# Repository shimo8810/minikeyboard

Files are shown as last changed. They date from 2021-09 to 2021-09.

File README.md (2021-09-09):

# minikeyboard

## 仕様

- 出力: CV/GATE 信号 (V/Hz)
- 音階: C4-B4 (多分)

## 回路図

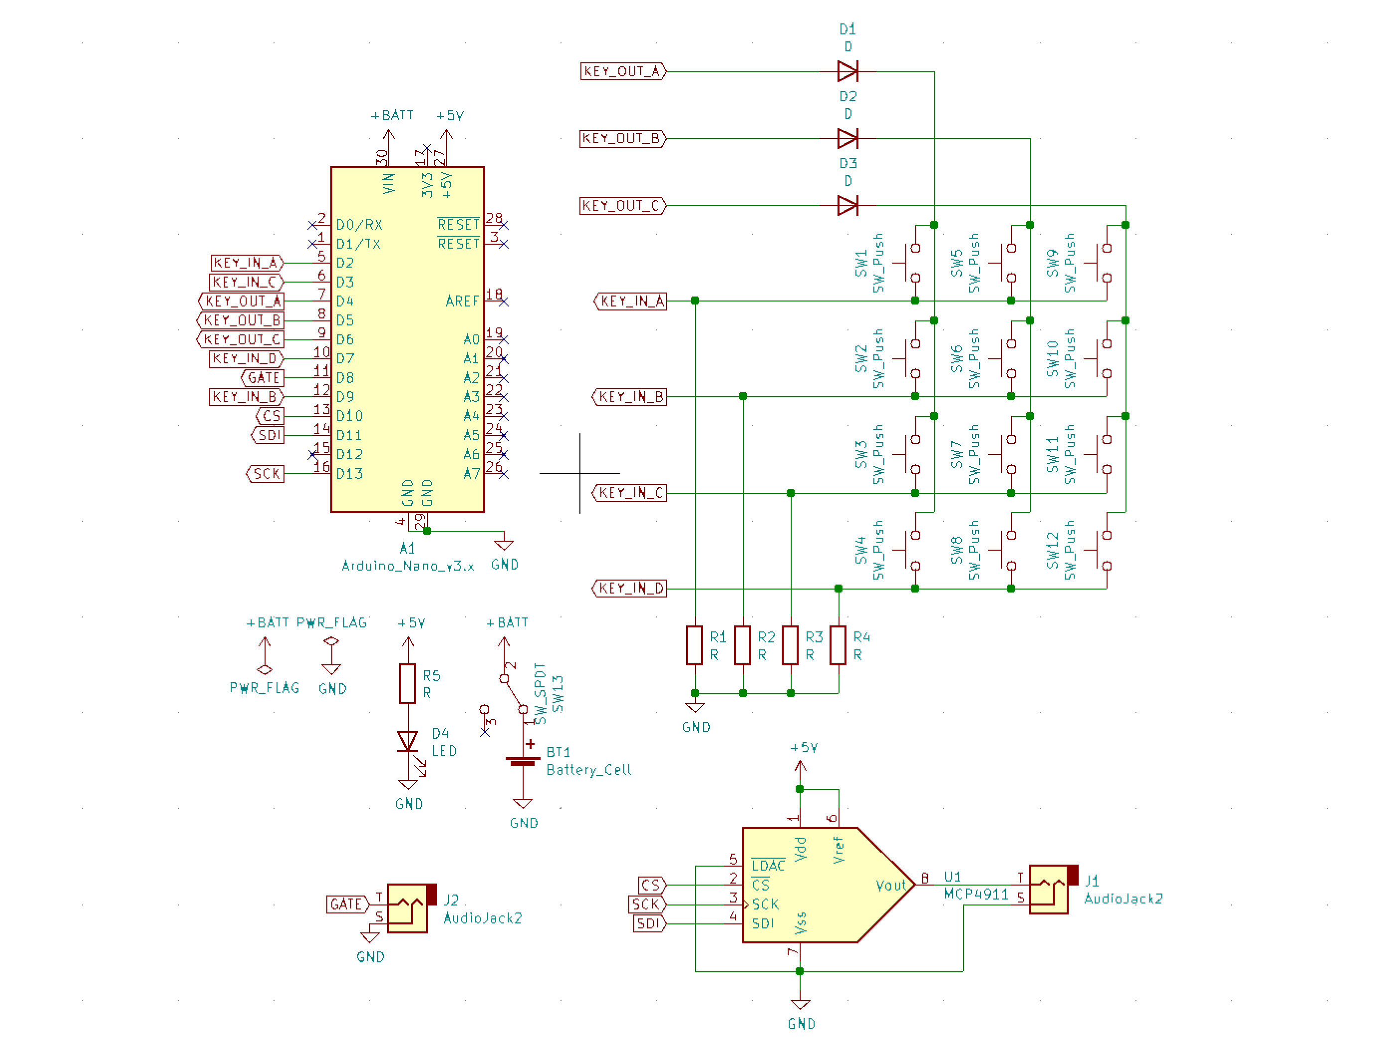
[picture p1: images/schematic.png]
schematic


## 配置

ユニバーサル基板用に配置
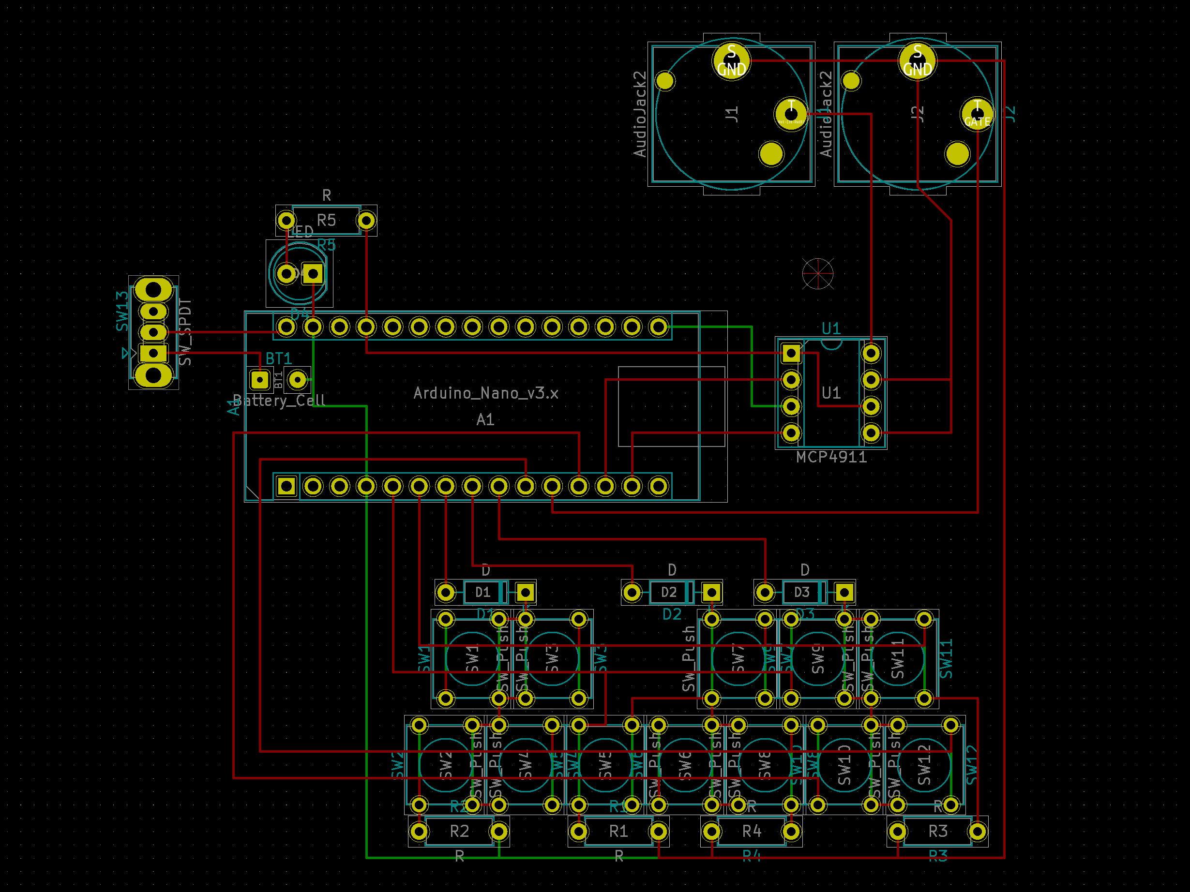
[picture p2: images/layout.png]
layout


## 完成品

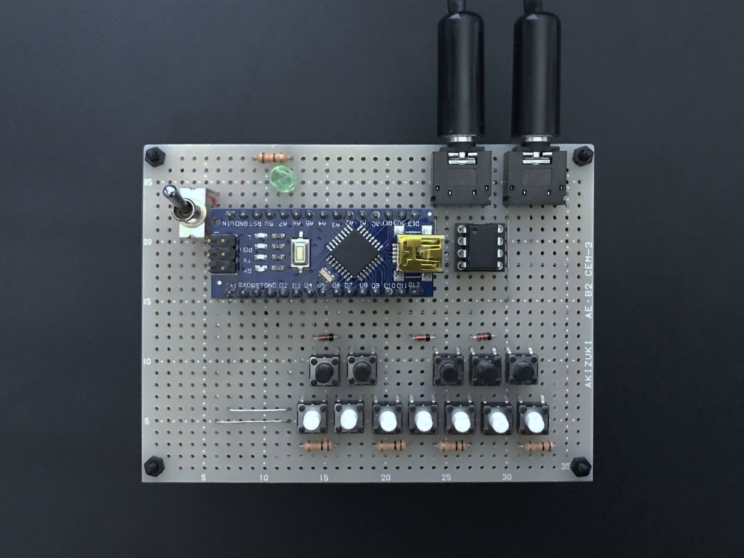
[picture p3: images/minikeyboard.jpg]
minikeyboard


## 参照･参考

- https://info.shimamura.co.jp/digital/support/2020/02/136051
- https://www.arduino.cc/reference/en/libraries/mcp_dac/
- https://moutakusan.hatenablog.com/entry/2020/10/23/071000

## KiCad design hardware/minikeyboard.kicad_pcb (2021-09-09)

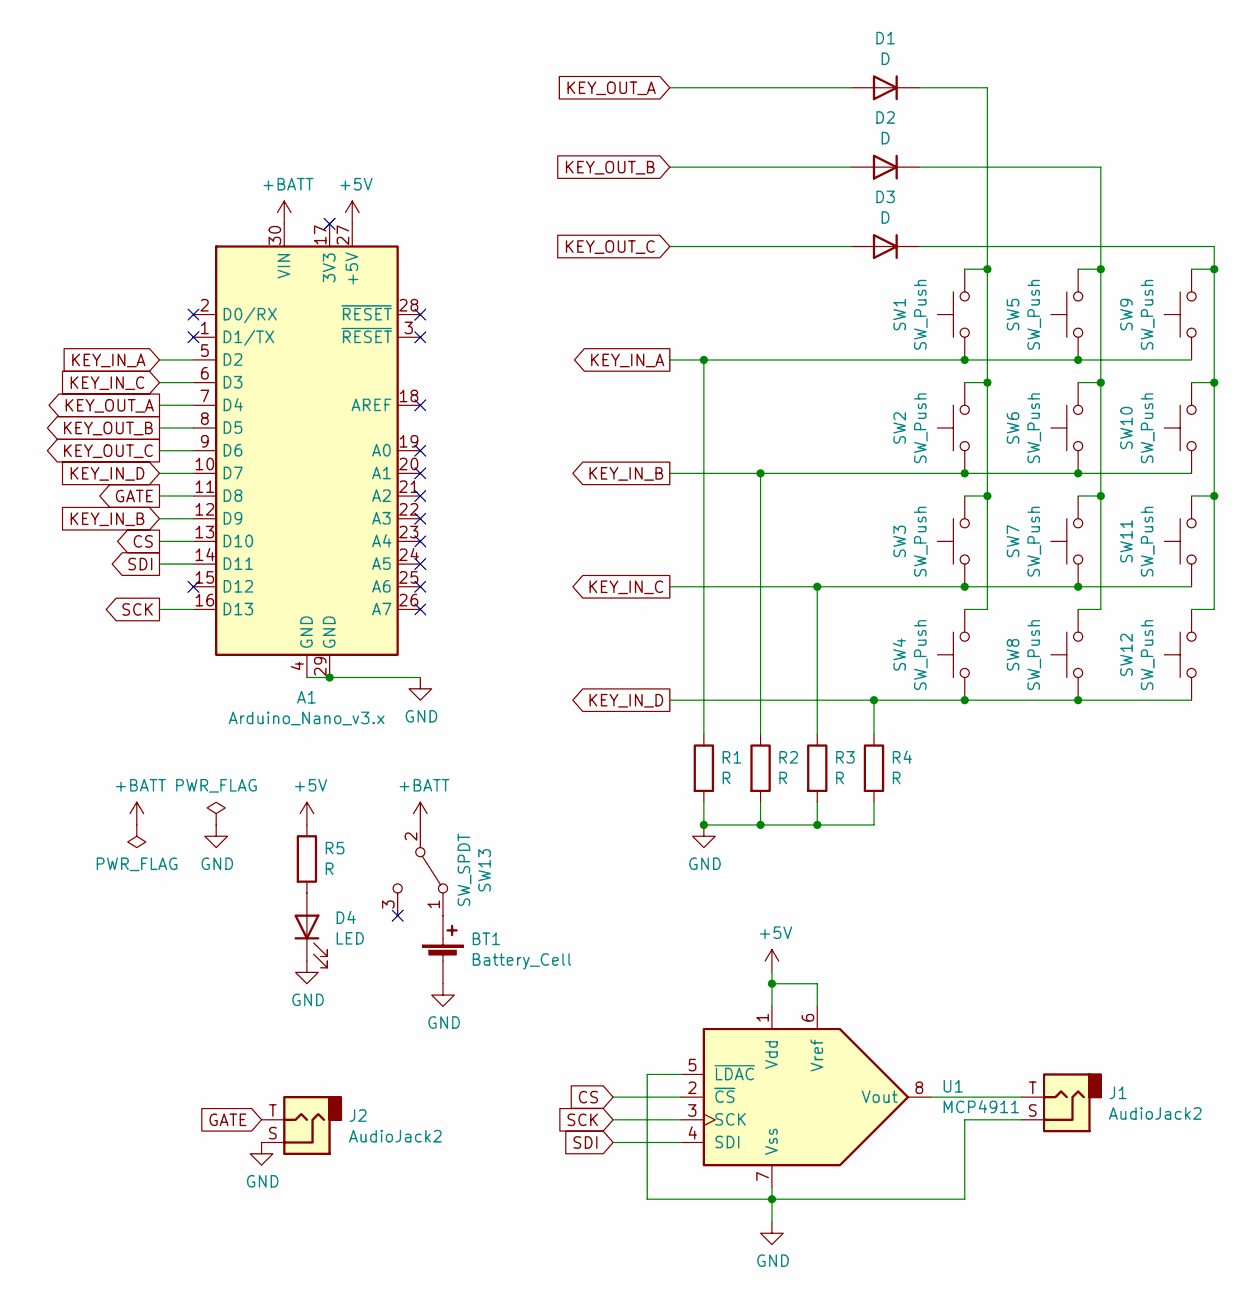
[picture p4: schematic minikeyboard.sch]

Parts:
A1: Arduino_Nano_v3.x; Arduino_Nano
BT1: Battery_Cell; SolderWire-0.1sqmm_1x02_P3.6mm_D0.4mm_OD1mm
D1, D2, D3: D; D_DO-35_SOD27_P7.62mm_Horizontal
D4: LED; LED_D5.0mm
J1, J2: AudioJack2; Jack_6.35mm_Neutrik_NJ2FD-V_Vertical
R1, R2, R3, R4, R5: R; R_Axial_DIN0207_L6.3mm_D2.5mm_P7.62mm_Horizontal
SW1, SW2, SW3, SW4, SW5, SW6, SW7, SW8, SW9, SW10, SW11, SW12: SW_Push; SW_Tactile_Straight_KSA0Axx1LFTR
SW13: SW_SPDT; SW_Slide_1P2T_CK_OS102011MS2Q
U1: MCP4911; DIP-8_W7.62mm_Socket

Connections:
+5V: A1.27 (+5V), R5.1, U1.1 (Vdd), U1.6 (Vref)
+BATT: A1.30 (VIN), SW13.2 (B)
CS: A1.13 (D10), U1.2 (~CS)
GATE: A1.11 (D8), J2.T
GND: A1.4 (GND), A1.29 (GND), BT1.2 (-), D4.1 (K), J1.S, J2.S, R1.2, R2.2, R3.2, R4.2, U1.5 (~LDAC), U1.7 (Vss)
KEY_IN_A: A1.5 (D2), R1.1, SW1.1, SW5.1, SW9.1
KEY_IN_B: A1.12 (D9), R2.1, SW2.1, SW6.1, SW10.1
KEY_IN_C: A1.6 (D3), R3.1, SW3.1, SW7.1, SW11.1
KEY_IN_D: A1.10 (D7), R4.1, SW4.1, SW8.1, SW12.1
KEY_OUT_A: A1.7 (D4), D1.2 (A)
KEY_OUT_B: A1.8 (D5), D2.2 (A)
KEY_OUT_C: A1.9 (D6), D3.2 (A)
unnamed: BT1.1 (+), SW13.1 (A)
unnamed: D1.1 (K), SW1.2, SW2.2, SW3.2, SW4.2
unnamed: D2.1 (K), SW5.2, SW6.2, SW7.2, SW8.2
unnamed: D3.1 (K), SW9.2, SW10.2, SW11.2, SW12.2
unnamed: D4.2 (A), R5.2
unnamed: J1.T, U1.8 (Vout)
SCK: A1.16 (D13), U1.3 (SCK)
SDI: A1.14 (D11), U1.4 (SDI)

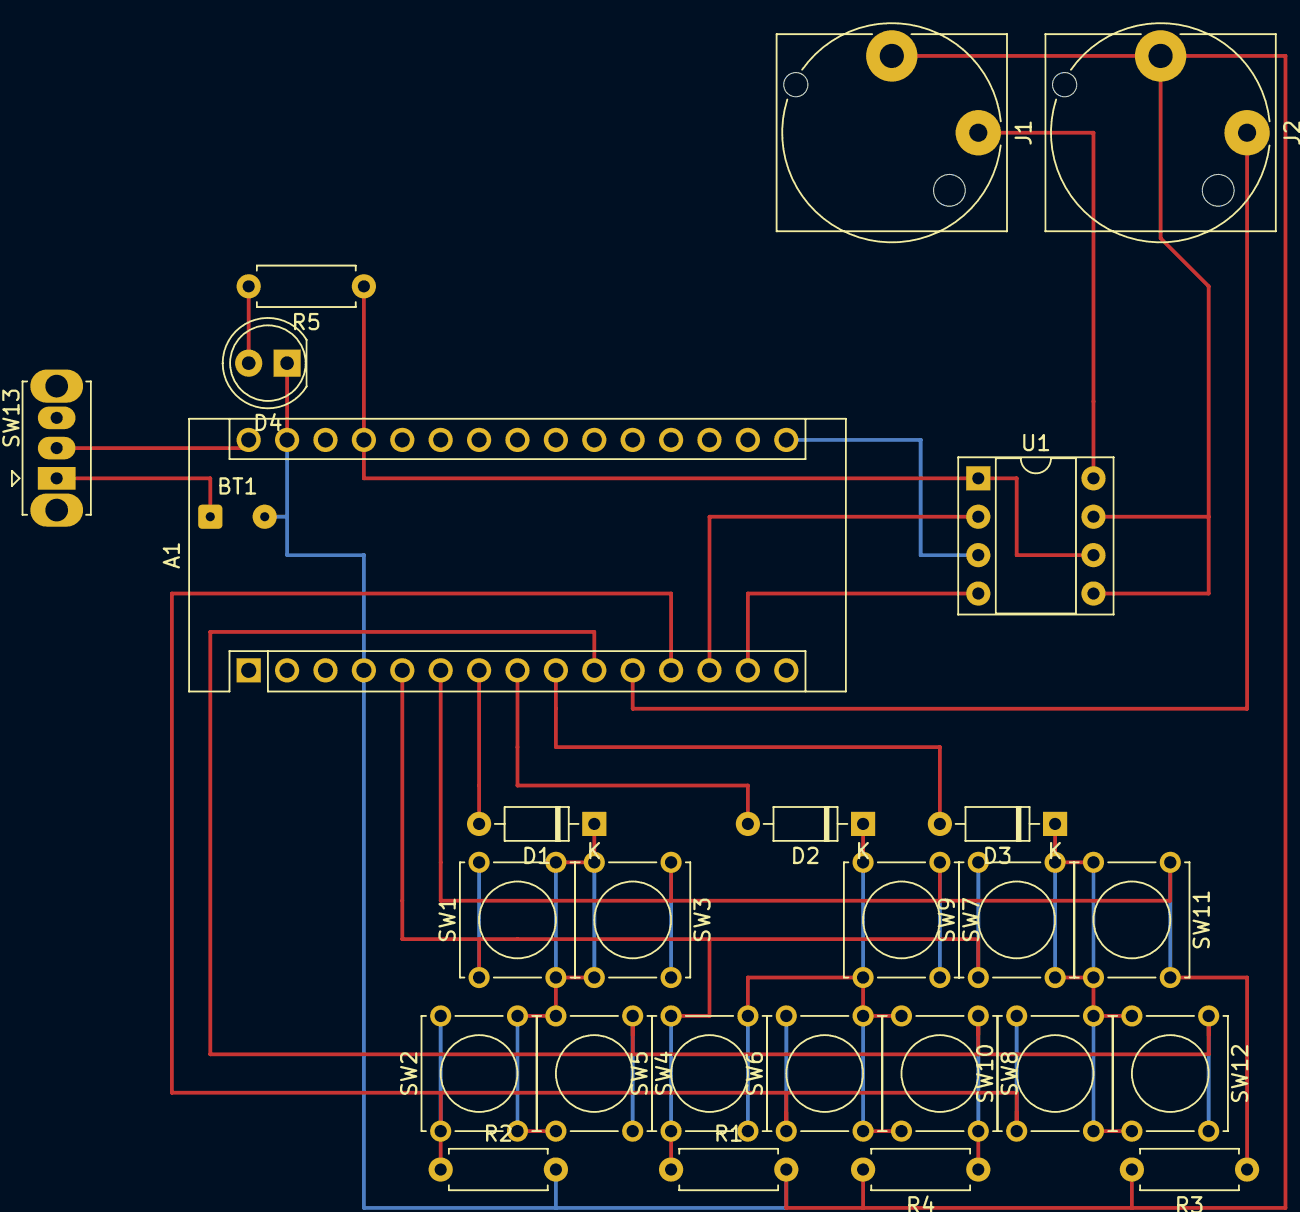
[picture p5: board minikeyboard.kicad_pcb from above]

Board: 2 copper layers, 27 parts (0 on the bottom side), 20 nets.

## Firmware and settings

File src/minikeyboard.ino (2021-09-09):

#include <math.h>

#include "MCP_DAC.h"

MCP4911 MCP;  // HW SPI

// freqs
constexpr double freqs[] = {
    277.183,  // C#
    311.127,  // D#
    293.665,  // D
    261.626,  // C
    329.628,  // E
    369.994,  // F#
    391.995,  // G
    349.228,  // F
    415.305,  // G#
    466.164,  // A#
    493.883,  // B
    440.000   // A
};

// log_2(55)
const double log2f0 = log(55.0) / M_LN2;

constexpr uint8_t NUM_KEY_IN = 4;
constexpr uint8_t NUM_KEY_OUT = 3;
constexpr uint8_t KEY_IN[] = {2, 3, 7, 9};
constexpr uint8_t KEY_OUT[] = {4, 5, 6};
constexpr uint8_t GATE = 8;

void setup() {
  // key matrix setup
  for (int i = 0; i < NUM_KEY_IN; ++i) {
    pinMode(KEY_IN[i], INPUT);
  }

  for (int i = 0; i < NUM_KEY_OUT; ++i) {
    pinMode(KEY_OUT[i], OUTPUT);
    digitalWrite(KEY_OUT[i], LOW);
  }

  // GATE setup
  pinMode(GATE, OUTPUT);
  digitalWrite(GATE, LOW);

  MCP.usesHWSPI();
  MCP.begin(10);
}

void loop() {
  bool pushed_sw = false;

  auto key = -1;

  for (auto i = 0; i < NUM_KEY_OUT; ++i) {
    digitalWrite(KEY_OUT[i], HIGH);
    for (auto j = 0; j < NUM_KEY_IN; ++j) {
      const auto val = digitalRead(KEY_IN[j]);
      if (val == HIGH) {
        pushed_sw = true;
        key = i * 4 + j;
        break;
      }
    }
    digitalWrite(KEY_OUT[i], LOW);
    if (pushed_sw) {
      break;
    }
  }

  if (pushed_sw) {
    // cv = log2(f/f0) = ln(f) / ln(2) - ln(f0) / ln(2), f0 = 110 / 2
    const auto cv = log(freqs[key]) / M_LN2 - log2f0;
    const auto val =
        static_cast<uint16_t>(cv * static_cast<double>(MCP.maxValue()) * 0.2);
    digitalWrite(GATE, HIGH);
    MCP.analogWrite(val, 0);

  } else {
    digitalWrite(GATE, LOW);
    MCP.analogWrite(0, 0);
  }
}

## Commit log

2021-09-09 [add] add hardware data
    [minikeyboard.kicad_pcb, minikeyboard.sch]
2021-09-09 [update] ignore kicad file
2021-09-09 [update] add sample images
